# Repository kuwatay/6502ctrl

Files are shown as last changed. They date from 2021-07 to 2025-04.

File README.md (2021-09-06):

# 6502ctrl
AVR-based supervisor for a w65c02 microcomputer based on z80ctrl https://github.com/jblang/z80ctrl

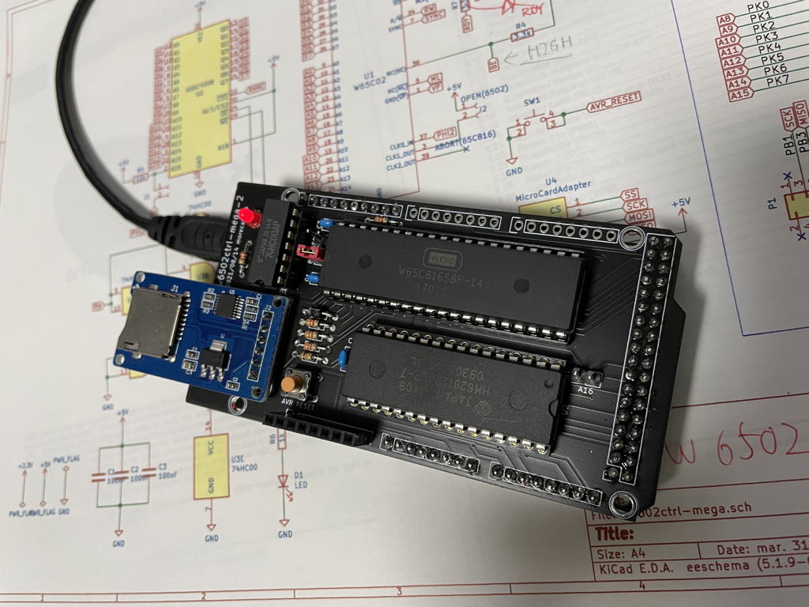
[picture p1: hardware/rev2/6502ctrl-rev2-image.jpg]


6502ctrl has the following features:
* Support W65C02 and 64KB(128KB) ram
* Console and other I/O are handled by DMA (ultra fast WAI instruction)
* Monitor with file management, memory inspector, and built-in 6502 disassembler
* Single-step debugging, breakpoints, and watchpoints to trace 6502 bus activity in real-time
* Arduino Shield style hardware (6502ctrl-mega)
* Flexible MIT-licensed firmware inhelited from z80ctrl

# Documentation

## Application
https://github.com/kuwatay/6502ctrl/wiki/Application

## Hardware note
https://github.com/kuwatay/6502ctrl/wiki/Hardware-of-6502ctrl-mega

## Supervisor sample session
https://github.com/kuwatay/6502ctrl/wiki/Sample-session-of--Supervisor

## DMA handling
https://github.com/kuwatay/6502ctrl/wiki/DMA-I-O-request

## MIT license
Permission is hereby granted, free of charge, to any person obtaining a copy of this software and associated documentation files (the "Software"), to deal in the Software without restriction, including without limitation the rights to use, copy, modify, merge, publish, distribute, sublicense, and/or sell copies of the Software, and to permit persons to whom the Software is furnished to do so, subject to the following conditions:

The above copyright notice and this permission notice shall be included in all copies or substantial portions of the Software.

THE SOFTWARE IS PROVIDED "AS IS", WITHOUT WARRANTY OF ANY KIND, EXPRESS OR IMPLIED, INCLUDING BUT NOT LIMITED TO THE WARRANTIES OF MERCHANTABILITY, FITNESS FOR A PARTICULAR PURPOSE AND NONINFRINGEMENT. IN NO EVENT SHALL THE AUTHORS OR COPYRIGHT HOLDERS BE LIABLE FOR ANY CLAIM, DAMAGES OR OTHER LIABILITY, WHETHER IN AN ACTION OF CONTRACT, TORT OR OTHERWISE, ARISING FROM, OUT OF OR IN CONNECTION WITH THE SOFTWARE OR THE USE OR OTHER DEALINGS IN THE SOFTWARE.

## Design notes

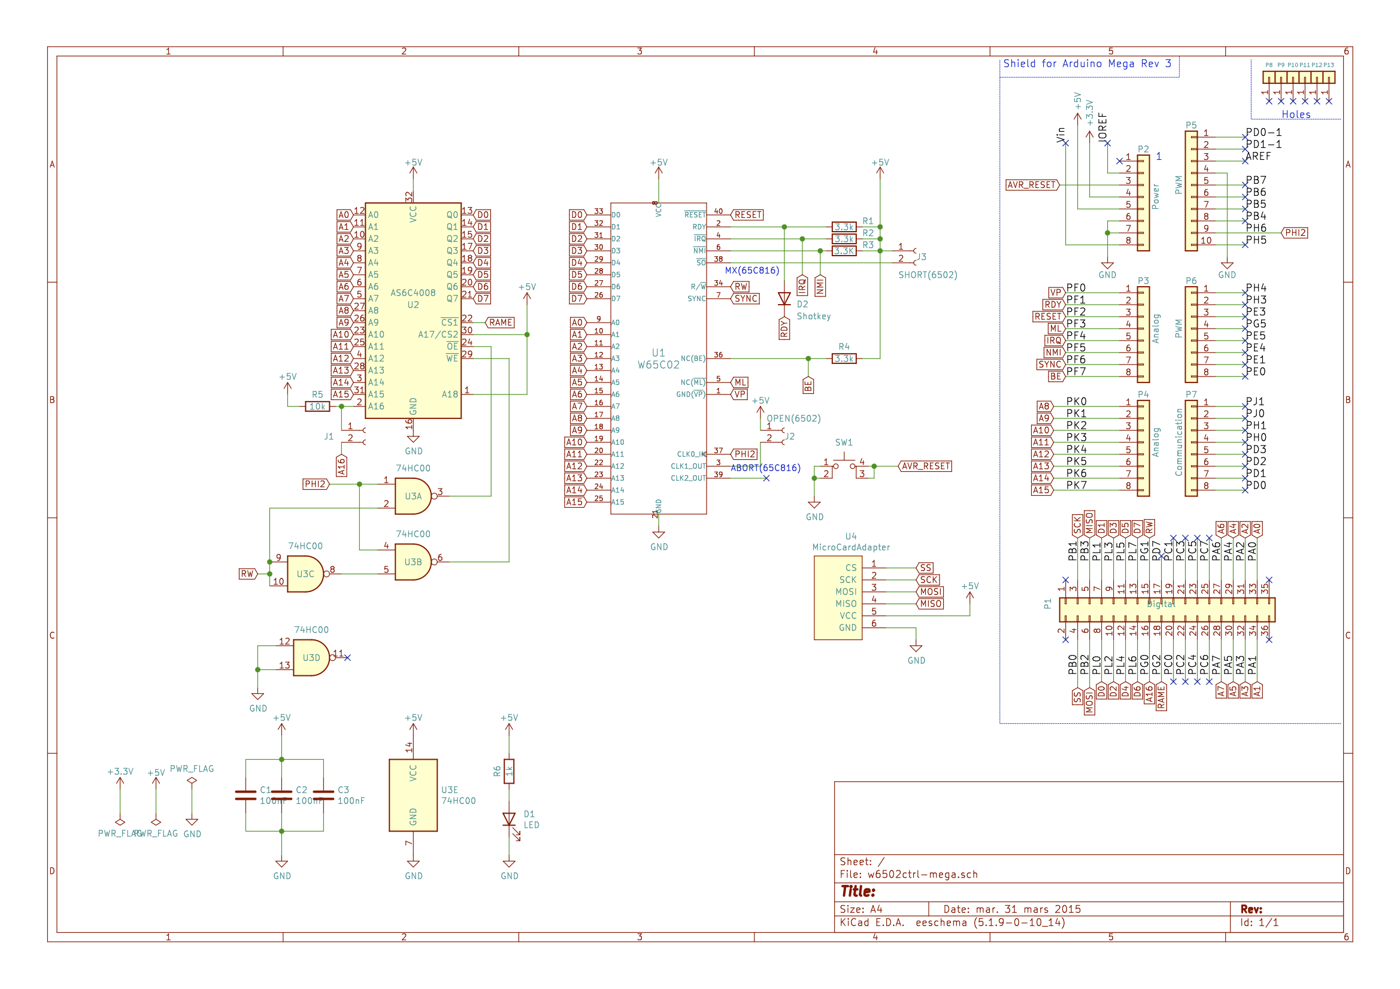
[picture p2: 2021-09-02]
hardware/rev2b/w65c02ctrl-mega2b-schematic.png

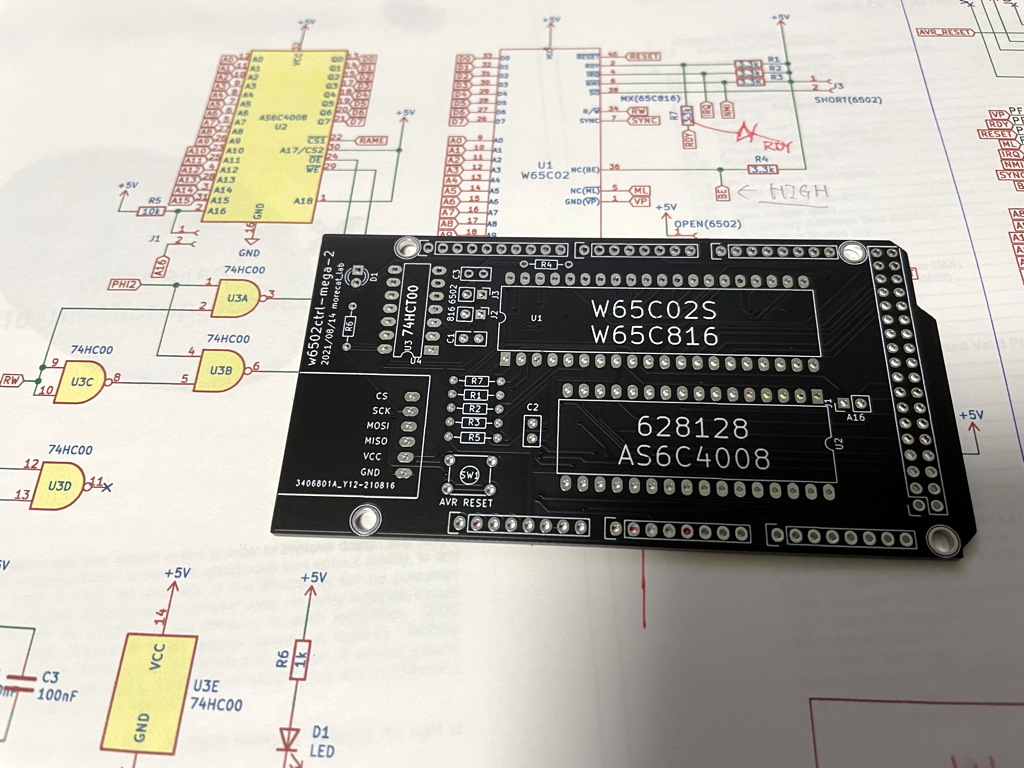
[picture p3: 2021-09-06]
hardware/rev2/6502ctrl-rev2-pcb.jpg

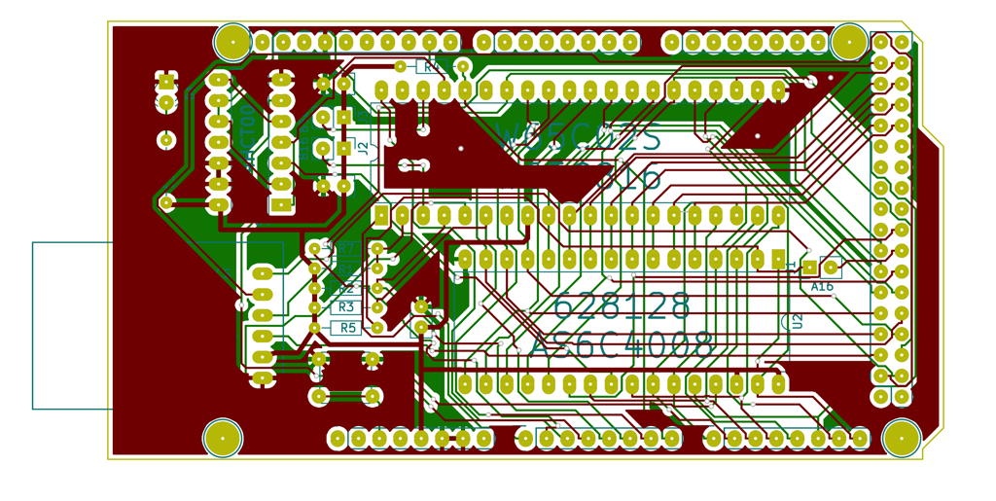
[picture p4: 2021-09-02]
hardware/rev2/6502ctrl-mega2-pcbimage.png

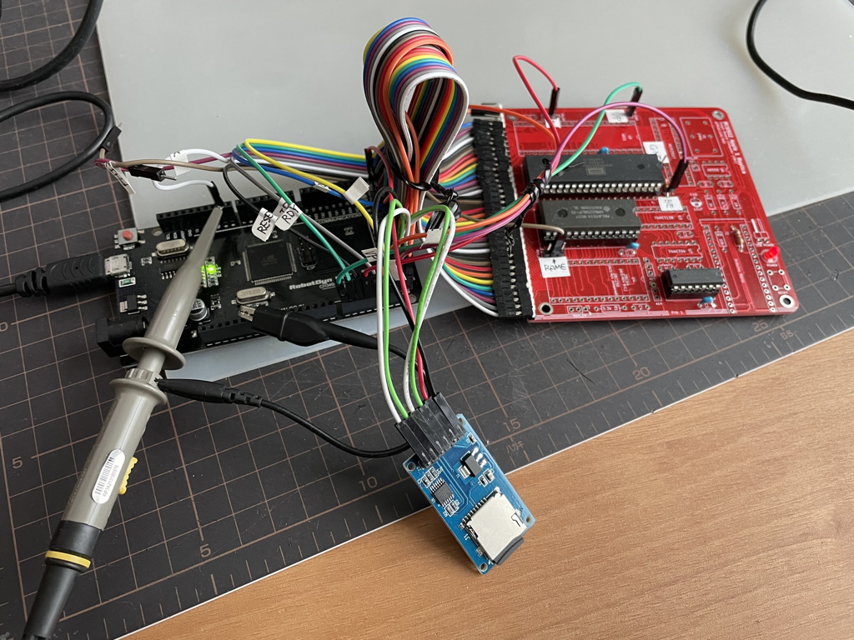
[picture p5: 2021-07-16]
hardware/prototype_6502ctrl.jpg

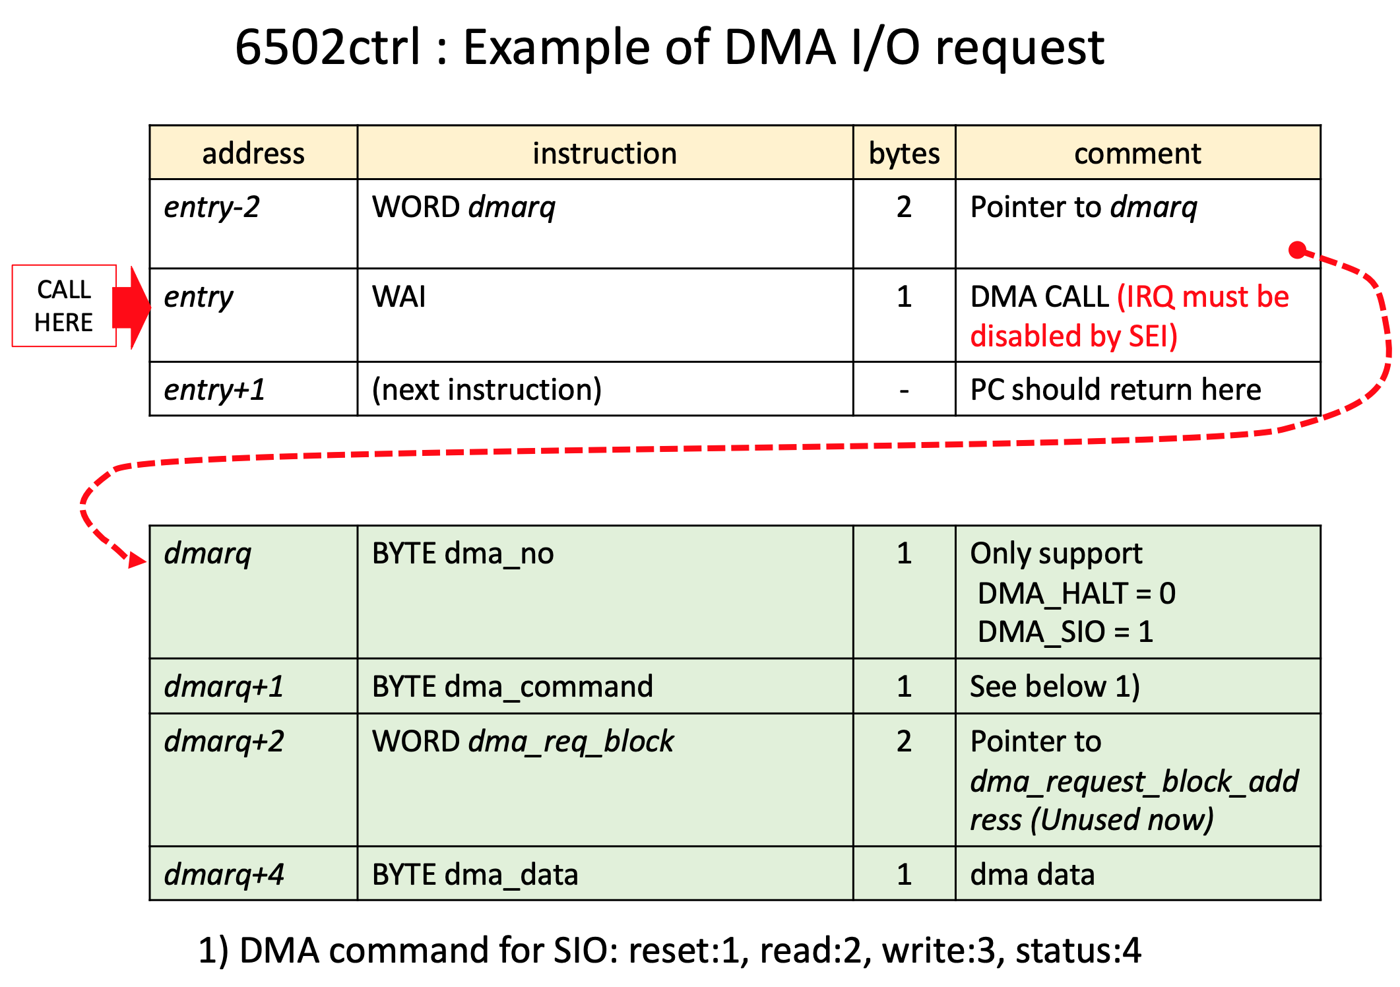
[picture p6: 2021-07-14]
DMA-request.png

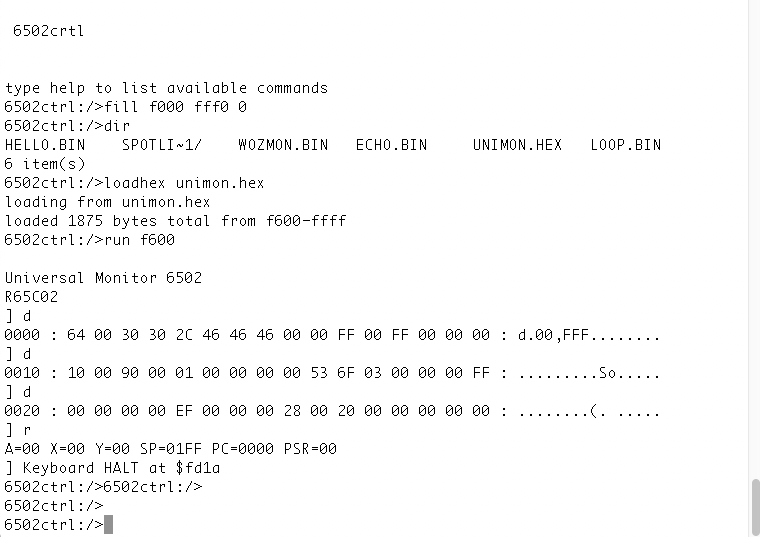
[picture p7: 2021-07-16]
examples/6502ctrl-univ-mon.png

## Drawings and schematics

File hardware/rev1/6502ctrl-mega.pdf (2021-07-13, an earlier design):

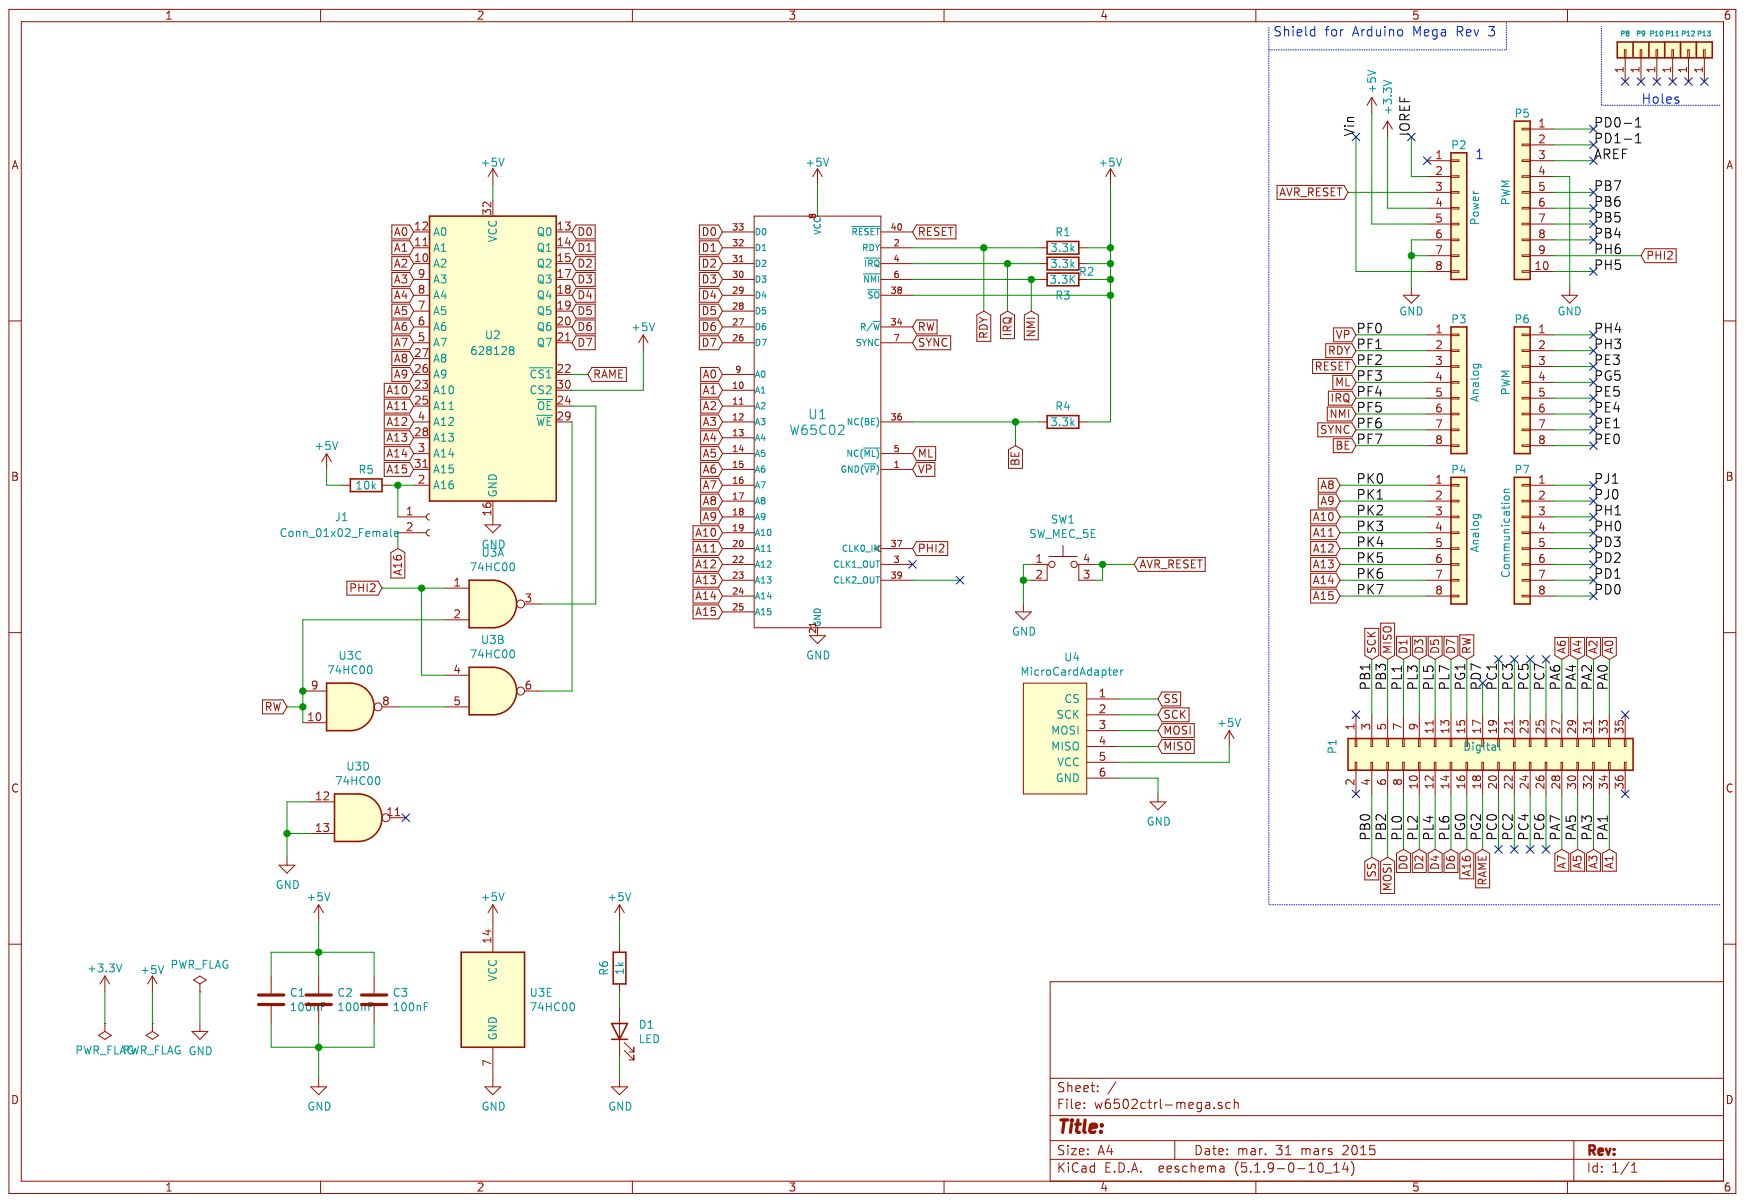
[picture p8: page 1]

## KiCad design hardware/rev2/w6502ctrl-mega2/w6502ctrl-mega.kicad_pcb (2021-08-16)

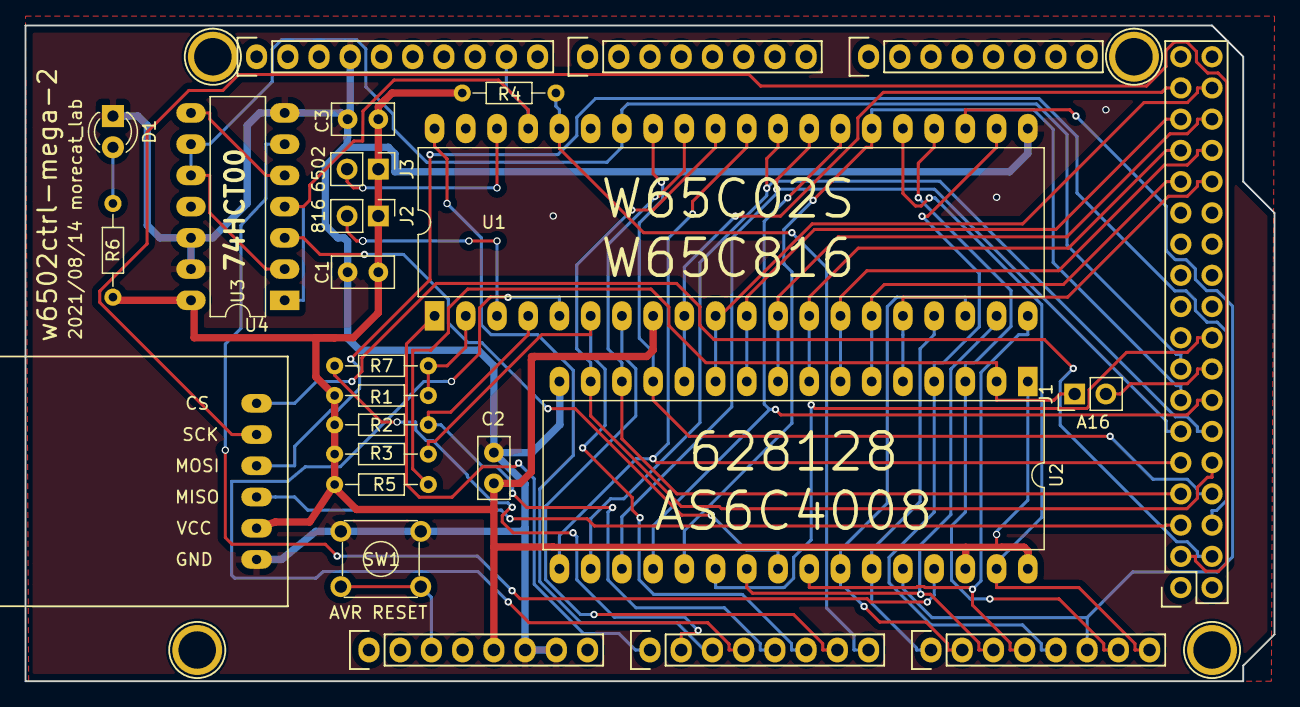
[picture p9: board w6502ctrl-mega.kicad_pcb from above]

Board: 2 copper layers, 101.6 x 53.3 mm, 30 parts (0 on the bottom side), 51 nets.

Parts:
C1, C2, C3: 100nF; C_Disc_D5.0mm_W2.5mm_P2.50mm
D1: LED; LED_D3.0mm
J1: Conn_01x02_Female; Pin_Header_Straight_1x02_Pitch2.54mm
J2: 816; Pin_Header_Straight_1x02_Pitch2.54mm
J3: 6502; Pin_Header_Straight_1x02_Pitch2.54mm
P1: Digital; Socket_Strip_Arduino_2x18
P2: Power; Socket_Strip_Arduino_1x08
P3, P4: Analog; Socket_Strip_Arduino_1x08
P5: PWM; Socket_Strip_Arduino_1x10
P6: PWM; Socket_Strip_Arduino_1x08
P7: Communication; Socket_Strip_Arduino_1x08
P8, P10, P11, P13: CONN_01X01; Arduino_1pin
R1, R2, R4, R7: 3.3k; R_Axial_DIN0204_L3.6mm_D1.6mm_P7.62mm_Horizontal
R3: 3.3K; R_Axial_DIN0204_L3.6mm_D1.6mm_P7.62mm_Horizontal
R5: 10k; R_Axial_DIN0204_L3.6mm_D1.6mm_P7.62mm_Horizontal
R6: 1k; R_Axial_DIN0204_L3.6mm_D1.6mm_P7.62mm_Horizontal
SW1: SW_MEC_5E; SW_TH_Tactile_Omron_B3F-10xx
U1: W65C02/816; DIP-40_W15.24mm_LongPads
U2: AS6C4008; DIP-32_W15.24mm_LongPads
U3: 74HC00; DIP-14_W7.62mm_LongPads
U4: MicroCardAdapter; MicroSDCardAdapter

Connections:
+5V: C1.1, C2.1, C3.1, J2.1, J3.1, P2.5, R1.1, R2.1, R3.1, R4.1, R5.2, R6.1, U1.8, U2.1, U2.30, U2.32, U3.14, U4.5
A0: P1.33, U1.9, U2.12
A1: P1.34, U1.10, U2.11
A2: P1.31, U1.11, U2.10
A3: P1.32, U1.12, U2.9
A4: P1.29, U1.13, U2.8
A5: P1.30, U1.14, U2.7
A6: P1.27, U1.15, U2.6
A7: P1.28, U1.16, U2.5
A8: P4.1, U1.17, U2.27
A9: P4.2, U1.18, U2.26
A10: P4.3, U1.19, U2.23
A11: P4.4, U1.20, U2.25
A12: P4.5, U1.22, U2.4
A13: P4.6, U1.23, U2.28
A14: P4.7, U1.24, U2.3
A15: P4.8, U1.25, U2.31
A16: J1.2, P1.16
AVR_RESET: P2.3, SW1.3, SW1.4
BE: P3.8, R4.2, U1.36
D0: P1.8, U1.33, U2.13
D1: P1.7, U1.32, U2.14
D2: P1.10, U1.31, U2.15
D3: P1.9, U1.30, U2.17
D4: P1.12, U1.29, U2.18
D5: P1.11, U1.28, U2.19
D6: P1.14, U1.27, U2.20
D7: P1.13, U1.26, U2.21
GND: C1.2, C2.2, C3.2, D1.1, P2.6, P2.7, P5.4, SW1.1, SW1.2, U1.21, U2.16, U3.7, U3.12, U3.13, U4.6
IRQ: P3.5, R2.2, U1.4
MISO: P1.5, U4.4
ML: P3.4, U1.5
MOSI: P1.6, U4.3
NMI: P3.6, R3.2, U1.6
unnamed: D1.2, R6.2
unnamed: J1.1, R5.1, U2.2
unnamed: J2.2, U1.3
unnamed: J3.2, U1.38
unnamed: R1.2, R7.1, U1.2
unnamed: U2.24, U3.3
unnamed: U2.29, U3.6
unnamed: U3.5, U3.8
PHI2: P5.9, U1.37, U3.1, U3.4
RAME: P1.18, U2.22
RDY: P3.2, R7.2
RESET: P3.3, U1.40
RW: P1.15, U1.34, U3.2, U3.9, U3.10
SCK: P1.3, U4.2
SS: P1.4, U4.1
SYNC: P3.7, U1.7
VP: P3.1, U1.1

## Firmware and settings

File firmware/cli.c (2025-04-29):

/* 6502ctrl (https://github.com/kuwatay/6502cttl)
 * Copyright 2021 Yoshitaka Kuwata a.k.a. morecat_lab
 *
 * based on z80ctrl (https://github.com/jblang/z80ctrl)
 * Copyright 2018 J.B. Langston
 *
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
 * THE SOFTWARE IS PROVIDED "AS IS", WITHOUT WARRANTY OF ANY KIND, EXPRESS OR
 * IMPLIED, INCLUDING BUT NOT LIMITED TO THE WARRANTIES OF MERCHANTABILITY, 
 * FITNESS FOR A PARTICULAR PURPOSE AND NONINFRINGEMENT. IN NO EVENT SHALL THE
 * AUTHORS OR COPYRIGHT HOLDERS BE LIABLE FOR ANY CLAIM, DAMAGES OR OTHER 
 * LIABILITY, WHETHER IN AN ACTION OF CONTRACT, TORT OR OTHERWISE, ARISING 
 * FROM, OUT OF OR IN CONNECTION WITH THE SOFTWARE OR THE USE OR OTHER 
 * DEALINGS IN THE SOFTWARE.
 */

/**
 * @file cli.c Monitor command-line interface
 */

#include <avr/pgmspace.h>
#include <avr/interrupt.h>
#include <stdint.h>
#include <stdio.h>
#include <string.h>
#include <stdlib.h>
#include <ctype.h>
#include <time.h>

#include "ff.h"
#include "bus.h"
#include "dmarq.h"
#include "w6502.h"
#include "ihex.h"
#include "util.h"
#include "disasm.h"
//#include "diskemu.h"
//#include "bdosemu.h"
#include "sioemu.h"
#include "diskio.h"
#include "uart.h"
#include "xmodem.h"
#include "filedma.h"
#ifdef USE_RTC
#include "rtc.h"
#endif
#ifdef SST_FLASH
#include "flash.h"
#endif
#include "ffwrap.h"

#ifdef HPDL1414
#include "hpdl1414.h"
#endif

/**
 * SD card filesystem
 */
FATFS fs;

/**
 * UART stdio stream
 */
FILE uart_str = FDEV_SETUP_STREAM(uart_putchar, uart_getchar, _FDEV_SETUP_RW);

uint8_t screenwidth = 80;
uint8_t screenheight = 24;

/**
 * Load an Intel HEX file from disk or stdin
 */
void cli_loadhex(int argc, char *argv[])
{
    FIL fil;
    FILE file;
    FRESULT fr;
    ihex_res result;
    if (argc < 2) {
        printf_P(PSTR("loading from console; enter blank line to cancel\n"));
        result = load_ihex(stdin);
    } else {
        printf_P(PSTR("loading from %s\n"), argv[1]);
        if ((fr = file_open(&fil, &file, argv[1], FA_READ)) != FR_OK)
            return;
        result = load_ihex(&file);
        file_close(&fil);
    }
    printf_P(PSTR("loaded %d bytes total from %04x-%04x"), result.total, result.min, result.max);
    if (result.errors > 0)
        printf_P(PSTR(" with %d errors"), result.errors);
    printf_P(PSTR("\n"));
}

/**
 * Save an Intel HEX file to disk or stdout
 */
void cli_savehex(int argc, char *argv[])
{
    FRESULT fr;
    FILE file;
    FIL fil;
    if (argc < 3) {
        printf_P(PSTR("usage: savehex <start> <end> [file]\n"));
        return;
    }
    uint32_t start = strtoul(argv[1], NULL, 16) & 0xfffff;
    uint32_t end = strtoul(argv[2], NULL, 16) & 0xfffff;
    if (argc == 4) {
        if ((fr = file_open(&fil, &file, argv[3], FA_WRITE | FA_CREATE_ALWAYS)) != FR_OK)
            return;
        if (save_ihex(start, end, &file) == EOF)
            printf_P(PSTR("error writing file"));
        file_close(&fil);
    } else {
        if (save_ihex(start, end, stdout) == EOF)
            printf_P(PSTR("error writing file"));
    }
}

#define MEM 0
#define TMS 1
#define FLASH 2

uint32_t loadbin(char *filename, uint8_t dest, int32_t start, uint32_t offset, uint32_t len)
{
    FIL fil;
    FRESULT fr;
    UINT br;
    uint8_t buf[512];
    uint16_t load = start;
    if (len == 0)
        len = 0x100000;
    if ((fr = file_open(&fil, NULL, filename, FA_READ)) != FR_OK)
        return -1;
    if ((fr = file_seek(&fil, offset)) == FR_OK) {
        if (start < 0) {
            // if starting address is not specified, get it from
            // the first two bytes of file a la C64 PRG files
            if (fr = file_read(&fil, &load, 2, &br) != FR_OK) {
                file_close(&fil);
                return 0;
            }
            start = load;
        }
        while ((fr = file_read(&fil, buf, sizeof buf, &br)) == FR_OK) {
            if (br > len)
                br = len;
            if (dest == MEM && br > 0) {
                mem_write_banked(start, buf, br);
            }
#ifdef SST_FLASH
            else if (dest == FLASH) {
                flash_write(start, buf, br);
            }
#endif
            if (br < sizeof buf)
                break;
            start += br;
            len -= br;
        }
    }
    file_close(&fil);
    return load;
}


/**
 * Load a binary file to specifie address from disk with optional offset and length
 */
void cli_loadbin(int argc, char *argv[])
{
    if (argc < 3) {
        printf_P(PSTR("usage: %s <start addr> <filename> [offset] [length]\n"), argv[0]);
        return;
    }
    uint8_t dest;
    if (strcmp_P(argv[0], PSTR("flash")) == 0)
        dest = FLASH;
    else if (strcmp_P(argv[0], PSTR("tmslbin")) == 0)
        dest = TMS;
    else
        dest = MEM;    
    uint32_t start = strtoul(argv[1], NULL, 16);
    char *filename = argv[2];
    uint32_t offset = 0;
    uint32_t len = 0;
    if (argc >= 4)
        offset = strtoul(argv[3], NULL, 16);
    if (argc >= 5)
        len = strtoul(argv[4], NULL, 16);
    loadbin(filename, dest, start, offset, len);
}

#if 0
#ifdef SST_FLASH
/**
 * Erase a flash sector or entire chip
 */
void cli_erase(int argc, char *argv[])
{
    if (argc < 2) {
        printf_P(PSTR("usage: erase <addr> | erase all\n"));
        return;
    }
    uint32_t addr;
    if (strcmp_P(argv[1], PSTR("all")) == 0)
        addr = 0x80000;
    else
        addr = strtoul(argv[1], NULL, 16);
    flash_erase(addr);
}
#endif
#endif

/**
 * Save an region of memory to a binary file on disk
 */
void cli_savebin(int argc, char *argv[])
{
    FRESULT fr;
    FILE file;
    FIL fil;
    UINT bw;
    uint16_t len = 256;
    uint8_t buf[256];
    if (argc < 4) {
        printf_P(PSTR("usage: savebin <start> <end> [file]\n"));
        return;
    }
    uint32_t start = strtoul(argv[1], NULL, 16) & 0xfffff;
    uint32_t end = strtoul(argv[2], NULL, 16) & 0xfffff;
    if ((fr = file_open(&fil, NULL, argv[3], FA_WRITE | FA_CREATE_ALWAYS)) == FR_OK) {
        while (start <= end) {
            if (end - start + 1 < len)
                len = end - start + 1;
            mem_read_banked(start, buf, len);
            if ((fr = file_write(&fil, buf, len, &bw)) != FR_OK)
                break;
            start += len;
        }
        file_close(&fil);
    }        
}

/**
 * Receive a file via xmodem
 */
void cli_xmrx(int argc, char *argv[])
{
    printf_P(PSTR("waiting for transfer to begin; press ^X twice to cancel\n"));
    xm_receive(argc - 1, &argv[1]);
}

/**
 * Transmit a file via xmodem
 */
void cli_xmtx(int argc, char *argv[])
{
    FIL fil;
    FILE file;
    FRESULT fr;
    UINT br;
    if (argc < 2) {
        printf_P(PSTR("usage: %s <file>\n"), argv[0]);
        return;
    }
    if ((fr = file_open(&fil, NULL, argv[1], FA_READ)) == FR_OK) {
        printf_P(PSTR("beginning transmission; press ^X twice to cancel\n"));
        xm_transmit(&fil);
        file_close(&fil);
    }
}


/**
 * Disassemble code from memory
 */
void cli_disasm(int argc, char *argv[])
{
    uint32_t start, end;
    if (argc < 2) {
        printf_P(PSTR("usage: disasm <start> [end]\n"));
        return;
    }
    start = strtoul(argv[1], NULL, 16) & 0xffff;
    if (argc < 3)
        end = start + 0xf;
    else
        end = strtoul(argv[2], NULL, 16) & 0xffff;
    disasm_mem(start, end);
}

/**
 * Generate a hex dump from memory
 */
void cli_dump(int argc, char *argv[])
{
  //    uint8_t tms = (strcmp_P(argv[0], PSTR("tmsdump")) == 0);
    if (argc < 2) {
        printf_P(PSTR("usage: %s [start] [end]\n"), argv[0]);
    }

    static uint32_t start = 0;
    uint32_t end = 0;
    if (argc >= 2)
        start = strtoul(argv[1], NULL, 16);
    if (argc >= 3)
        end = strtoul(argv[2], NULL, 16);
    
    uint8_t buf[16];

    uint8_t buflen = 16;
    if (screenwidth < 80)
        buflen = 8;

    if (end == 0)
        end = start + (screenheight - 3) * buflen;

    printf_P(PSTR("ADDR   "));
    for (uint8_t j = 0; j < buflen; j++) {
        printf("+%X ", j);
        if (j % 4 == 3 && screenwidth > 41)
            printf_P(PSTR(" "));
    }
    if (screenwidth > 40)
        printf_P(PSTR(" "));
    for (uint8_t j = 0; j < buflen; j++)
        printf_P(PSTR("%X"), j);
    printf_P(PSTR("\n"));

    
    for (uint32_t i = start; i <= end;) {
        printf_P(PSTR("%05lX  "), base_addr + i);
            mem_read_banked(i, buf, buflen);
        for (uint8_t j = 0; j < buflen; j++) {
            printf_P(PSTR("%02X "), buf[j]);
            if (j % 4 == 3 && screenwidth > 41)
                printf_P(PSTR(" "));
        }
        if (screenwidth > 40)
            printf_P(PSTR(" "));
        for (uint8_t j = 0; j < buflen; j++, i++) {
            if (0x20 <= buf[j] && buf[j] <= 0x7e)
                printf_P(PSTR("%c"), buf[j]);
            else
                printf_P(PSTR("."));
        }
        printf_P(PSTR("\n"));
    }
    start = end + buflen;
}

/**
 * Run the processor at full speed from an optional starting address
 */
void cli_run(int argc, char *argv[])
{
    if (argc >= 2) {
        uint32_t addr = strtoul(argv[1], NULL, 16) & 0xfffff;
        w6502_reset(addr);
    }
    w6502_run();
}


/**
 * Reset the processor and optionally set up a reset vector
 */
void cli_reset(int argc, char *argv[])
{
    uint32_t addr = 0;
    if (argc >= 2) {
        addr = strtoul(argv[1], NULL, 16) & 0xfffff;
    }
    w6502_reset(addr);
}

/**
 * Run the processor with debugging enabled from an optional starting address
 */
void cli_debug(int argc, char *argv[])
{
    if (argc >= 2) {
        uint32_t addr = strtoul(argv[1], NULL, 16) & 0xfffff;
        w6502_reset(addr);
    }
    w6502_debug(1);
}

/**
 * Run the processor for a specified number of instructions
 */
void cli_step(int argc, char *argv[])
{
    uint32_t cycles = 1;
    if (argc >= 2)
        cycles = strtoul(argv[1], NULL, 10);            
    w6502_debug(cycles);
}

/**
 * Reduce the W6502 clock speed by the specified factor
 */
void cli_clkdiv(int argc, char *argv[])
{
    uint8_t tmp = 0;
    if (argc >= 2)
        tmp = strtoul(argv[1], NULL, 10);
    if (tmp > 1)
        clkdiv = tmp;
    else
        printf_P(PSTR("usage: clkdiv <divider>; minimum divider is 2\n"));
    uint16_t freq = F_CPU / clkdiv / 1000;
    printf_P(PSTR("current speed is %u.%03u MHz (clkdiv=%d)\n"), freq/1000, freq-(freq/1000)*1000, clkdiv);
}

/**
 * Set screen size
 */
void cli_screen(int argc, char *argv[])
{
    uint8_t tmpwidth = 0, tmpheight = 0;
    if (argc >= 2)
        tmpwidth = strtoul(argv[1], NULL, 10);
    if (argc >= 3)
        tmpheight = strtoul(argv[2], NULL, 10);
    if (tmpwidth >= 40)
        screenwidth = tmpwidth;
    if (tmpheight >= 24)
        screenheight = tmpheight;
        printf_P(PSTR("usage: screen <width> <height>\n"));
    uint16_t freq = F_CPU / clkdiv / 1000;
    printf_P(PSTR("current screen size is %dx%d\n"), screenwidth, screenheight);
}

/**
 * Interrogate or set breakpoint and watch ranges
 */
void cli_breakwatch(int argc, char *argv[])
{
    range *ranges;
    uint8_t type;

    if (strcmp_P(argv[0], PSTR("break")) == 0)
        ranges = breaks;
    else
        ranges = watches;
    
    // If no parameters given, show current status
    if (argc == 1) {
        printf_P(PSTR("%s status:\n"), argv[0]);
        for (uint8_t i = 0; i < DEBUGCNT; i++) {
            if (!ENABLED(ranges, i))
                printf_P(PSTR("\t%S\tdisabled\n"), strlookup(debug_names, i));
            else
                printf_P(PSTR("\t%S\t%04x-%04x\n"), strlookup(debug_names, i), ranges[i].start, ranges[i].end);
        }
        printf_P(PSTR("\nusage:\n\t%s <type> [start] [end]\n"), argv[0]);
        printf_P(PSTR("\t%s <type> off to disable type\n"), argv[0]);
        printf_P(PSTR("\t%s off to disable all\n"), argv[0]);
        return;
    }
    if (strcmp_P(argv[1], PSTR("off")) == 0) {
        // turn off all ranges
        for (uint8_t i = 0; i < DEBUGCNT; i++) {
            ranges[i].start = 0xffff;
            ranges[i].end = 0;
        }
        return;
    } else {
        // find the debugging type that the user specified
        for (type = 0; type < DEBUGCNT; type++)
            if (strcmp_P(argv[1], strlookup(debug_names, type)) == 0)
                break;
        if (type == DEBUGCNT) {
            printf_P(PSTR("error: unknown type\n"));
            return;
        }
        if (argc == 2) {
            // no range specified, enable for 0x0000-0xffff
            ranges[type].start = 0;
            ranges[type].end = 0xffff;
        } else if (argc >= 3) {
            if (strcmp_P(argv[2], PSTR("off")) == 0) {
                ranges[type].start = 0xffff;
                ranges[type].end = 0;
            } else {
                // get starting address
                ranges[type].start = strtoul(argv[2], NULL, 16);
                if (argc >= 4)
                    // get ending address if specified
                    ranges[type].end = strtoul(argv[3], NULL, 16);
                else
                    // if no ending address, start and end are the same
                    ranges[type].end = ranges[type].start;
            }
        }
    }
}

#if 0
/**
 * Enable/disable BDOS debug messages
 */
void cli_bdosdbg(int argc, char *argv[])
{
    if (argc == 2) {
        if (strcmp_P(argv[1], PSTR("on")) == 0)
            bdos_debug = 1;
        else if (strcmp_P(argv[1], PSTR("off")) == 0)
            bdos_debug = 0;
    }
    if (bdos_debug)
        printf("bdos debug is enabled\n");
    else
        printf("bdos debug is disabled\n");
}
#endif

/**
 * Enable/disable DMA debug messages
 */
void cli_dmadbg(int argc, char *argv[])
{
    if (argc == 2) {
        if (strcmp_P(argv[1], PSTR("on")) == 0)
            dma_debug = 1;
        else if (strcmp_P(argv[1], PSTR("off")) == 0)
            dma_debug = 0;
    }
    if (dma_debug)
        printf("dma debug is enabled\n");
    else
        printf("dma debug is disabled\n");
}

/**
 * Change default directory
 */
void cli_chdir(int argc, char *argv[])
{
 	FRESULT fr;

    if (argc < 2) {
        printf_P(PSTR("usage: cd <directory>\n"));
        return;
    }

    fr = f_chdir(argv[1]);
    if (fr)
        printf_P(PSTR("error changing directory: %S\n"), strlookup(fr_text, fr));
}

/**
 * Create a directory
 */
void cli_mkdir(int argc, char *argv[])
{
 	FRESULT fr;

    if (argc < 2) {
        printf_P(PSTR("usage: mkdir <dir>\n"));
        return;
    }

    for (uint8_t i = 1; i < argc; i++) {
        if (fr = f_mkdir(argv[i]))
            printf_P(PSTR("error making directory %s: %S\n"), argv[i], strlookup(fr_text, fr));
    }
}

/**
 * Show a directory of files on the SD Card
 */
void cli_dir(int argc, char *argv[])
{
    FRESULT fr;
    FILINFO finfo;
    DIR dir;
	UINT cnt;
    char *dirname;
    char *glob;
    char buf[14];

    if (argc == 1) {
        dirname = ".";
        glob = NULL;
    } else {
        dirname = argv[1];
        glob = file_splitpath(dirname);
    }

    if (glob == NULL) {
        fr = f_opendir(&dir, dirname);
        if (fr == FR_NO_PATH || fr == FR_INVALID_NAME) {
            glob = dirname;
            dirname = ".";
        } else if (fr != FR_OK) {
            printf_P(PSTR("error opening directory: %S\n"), strlookup(fr_text, fr));
            return;
        }
    }

    if (glob == NULL) {
        fr = f_readdir(&dir, &finfo);
    } else {
        fr = f_findfirst(&dir, &finfo, dirname, glob);
    }

    uint8_t maxcnt = screenwidth / 13;

    cnt = 0;
    for(;;) {
        if (fr != FR_OK) {
            printf_P(PSTR("error reading directory: %S\n"), strlookup(fr_text, fr));
            break;
        }
        if ((cnt % maxcnt == 0 && cnt != 0) || !finfo.fname[0])
            printf_P(PSTR("\n"));
        if (!finfo.fname[0]) 
            break;
        strcpy(buf, finfo.fname);
        if (finfo.fattrib & AM_DIR)
            strcat(buf, "/");
        printf_P(PSTR("%-13s"), buf);
        cnt++;
        if (glob == NULL)
            fr = f_readdir(&dir, &finfo);
        else
            fr = f_findnext(&dir, &finfo);
    }
    if (cnt)
        printf_P(PSTR("%u item(s)\n"), cnt);
    else
        printf_P(PSTR("file not found\n"));
    
    f_closedir(&dir);
}

void cli_copy(int argc, char *argv[])
{
    if (argc < 3) {
        printf_P(PSTR("usage: %s <src>... <dest>\n"), argv[0]);
        return;
    }
    file_iterate(file_copy, argc-2, &argv[1], argv[argc-1]);
}

void cli_ren(int argc, char *argv[])
{
    if (argc < 3) {
        printf_P(PSTR("usage: %s <src>... <dest>\n"), argv[0]);
        return;
    }
    file_iterate(file_rename, argc-2, &argv[1], argv[argc-1]);
}

void cli_del(int argc, char *argv[])
{
    if (argc < 2) {
        printf_P(PSTR("usage: %s <file>...\n"), argv[0]);
        return;
    }
    file_iterate(file_delete, argc-1, &argv[1], NULL);
}

/**
 * Fill memory with a specified byte for a specified range
 */
void cli_fill(int argc, char *argv[])
{
    if (argc != 4) {
        printf_P(PSTR("usage: fill <start> <end> <value>\n"));
        return;
    }
    //    uint8_t tms = (strcmp_P(argv[0], PSTR("tmsfill")) == 0);
    uint32_t start = strtoul(argv[1], NULL, 16) & 0xfffff;
    uint32_t end = strtoul(argv[2], NULL, 16) & 0xfffff;
    uint8_t buf[256];
    if (strcmp_P(argv[3], PSTR("asc")) == 0) {
        for (uint16_t i = 0; i < 256; i++)
            buf[i] = i;
    } else if (strcmp_P(argv[3], PSTR("desc")) == 0) {
        for (uint16_t i = 0; i < 256; i++)
            buf[i] = 255 - i;
    } else {
        uint8_t value = strtoul(argv[3], NULL, 16) & 0xff;
        for (uint16_t i = 0; i < 256; i++)
            buf[i] = value;
    }
    
    for (;;) {
        if (end - start > 256) {
                mem_write_banked(start, buf, 256);
            start += 256;
        } else {
                mem_write_banked(start, buf, end - start + 1);
            break;
        }
    }
}

/**
 * Poke values into memory
 */
void cli_poke(int argc, char *argv[])
{
    uint8_t value;
    if (argc < 2)
        printf_P(PSTR("usage: poke <start> [value...]\n"));
    uint32_t addr = strtoul(argv[1], NULL, 16);
    if (argc >= 3) {
        for (uint8_t i = 2; i < argc; i++) {
            value = strtoul(argv[i], NULL, 16) & 0xff;
            mem_write_banked(addr++, &value, 1);
        }
        return;
    }
    printf_P(PSTR("enter valid hex to replace; blank to leave unchanged; 'x' to exit.\n"));
    for (;;) {
        char buf[16];
        mem_read_banked(addr, &value, 1);
        printf_P(PSTR("%05lX=%02X : "), addr + base_addr, value);
        if (fgets(buf, sizeof buf - 1, stdin) == NULL) {
            break;
        } else {
            char *end;
            value = strtoul(buf, &end, 16);
            if (*buf == '\n' || *buf == '\r' || *buf == '\0') {
                addr++;
                continue;
            } else if (end == buf) {
                break;
            } else {
                mem_write_banked(addr, &value, 1);
                addr++;
            }
        }
    }
    
}

#if 0
#if defined(BANK_PORT) || defined(BANK_BASE)

/**
 * Set the base address in memory
 */
void cli_base(int argc, char *argv[])
{
    if (argc == 2) {
        if (base_addr & 0xFFFF != 0)
            printf_P(PSTR("base address must be a multiple of 0x10000"));
        else
            base_addr = strtoul(argv[1], NULL, 16) & 0xF0000;
    } else {
        printf_P(PSTR("current base address is %05lX\n"), base_addr);
    }
}
#endif
#endif

/**
 * Boot from a disk
 */
#if 0
void cli_boot(int argc, char*argv[])
{
    if (argc == 2) {
        drive_mount(0, argv[1]);
    }
    if(drive_bootload()) {
        w6502_reset(0);
        w6502_run();
    }
}
#endif

/**
 * Display the bus status
 */
void cli_bus(int argc, char *argv[]) 
{
  bus_stat status = bus_status();
  bus_log(status);
#ifdef HPDL1414
  hpdl1414_disp(status);
#endif
}

#if 0
/**
 * Mount a disk image
 */
void cli_mount(int argc, char *argv[])
{
    if (argc != 3) {
        printf_P(PSTR("usage: mount <drive #> <filename>\n"));
        return;
    }
    uint8_t drv = strtoul(argv[1], NULL, 10);
    char *filename = argv[2];
    drive_mount(drv, filename);
}
#endif

#if 0
/**
 * Unmount a disk image
 */
void cli_unmount(int argc, char *argv[])
{
    if (argc != 2) {
        printf_P(PSTR("usage: unmount <drive #>\n"));
        return;
    }
    uint8_t drv = strtoul(argv[1], NULL, 10);
    drive_unmount(drv);
}
#endif

#if 0
/**
 * Display or set the date on the RTC
 */
#ifdef USE_RTC
void cli_date(int argc, char *argv[])
{
    struct tm date;
    char datestr[30];
    if (argc < 8) {
        rtc_get_date(&date);
        printf_P(PSTR("The time is %d:%02d:%02d on %d/%d/%02d\n"), date.tm_hour, date.tm_min, date.tm_sec, date.tm_mon, date.tm_mday, date.tm_year);
        printf_P(PSTR("usage: date <yy mm dd wd hh mm ss>\n"));
        return;
    }

    date.tm_year = strtoul(argv[1], NULL, 10);
    date.tm_mon = strtoul(argv[2], NULL, 10);
    date.tm_mday = strtoul(argv[3], NULL, 10);
    date.tm_wday = strtoul(argv[4], NULL, 10);
    date.tm_hour = strtoul(argv[5], NULL, 10);
    date.tm_min = strtoul(argv[6], NULL, 10);
    date.tm_sec = strtoul(argv[7], NULL, 10);
    rtc_set_date(&date);
}
#endif
#endif
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
int main(void)
{
    FRESULT fr;

    uart_init(0, UBRR115200);
    uart_init(1, UBRR115200);
    stdout = stdin = &uart_str;

    disk_initialize(DRV_MMC);
    if ((fr = f_mount(&fs, "", 1)) != FR_OK)
      printf_P(PSTR("error mounting drive: %S\n"), strlookup(fr_text, fr));

    bus_init();

#ifdef HPDL1414    
    hpdl1414_init();
    hpdl1414_clear();
    hpdl1414_strcpy_P(PSTR("6502CTRL_RDY"));
#endif

    //cli_exec(AUTOEXEC);
    cli_loop();
}

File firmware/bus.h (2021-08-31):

/* 6502ctrl (https://github.com/kuwatay/6502cttl)
 * Copyright 2021 Yoshitaka Kuwata a.k.a. morecat_lab
 *
 * based on z80ctrl (https://github.com/jblang/z80ctrl)
 * Copyright 2018 J.B. Langston
 *
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
 * THE SOFTWARE IS PROVIDED "AS IS", WITHOUT WARRANTY OF ANY KIND, EXPRESS OR
 * IMPLIED, INCLUDING BUT NOT LIMITED TO THE WARRANTIES OF MERCHANTABILITY, 
 * FITNESS FOR A PARTICULAR PURPOSE AND NONINFRINGEMENT. IN NO EVENT SHALL THE
 * AUTHORS OR COPYRIGHT HOLDERS BE LIABLE FOR ANY CLAIM, DAMAGES OR OTHER 
 * LIABILITY, WHETHER IN AN ACTION OF CONTRACT, TORT OR OTHERWISE, ARISING 
 * FROM, OUT OF OR IN CONNECTION WITH THE SOFTWARE OR THE USE OR OTHER 
 * DEALINGS IN THE SOFTWARE.
 */

/**
 * @file bus.h Low-level control of the Z80 bus
 */

#ifndef BUS_H
#define BUS_H

#include <avr/io.h>

/**
 * Address Bus
 */

#define ADDRLO_DDR DDRA
#define ADDRLO_PORT PORTA
#define ADDRLO_PIN PINA

#ifdef MEGA
#define ADDRHI_DDR DDRK
#define ADDRHI_PORT PORTK
#define ADDRHI_PIN PINK
#else
#define ADDRHI_DDR DDRC
#define ADDRHI_PORT PORTC
#define ADDRHI_PIN PINC
#endif

#define ADDR_INPUT (ADDRLO_DDR = 0x00, ADDRHI_DDR = 0x00)
#define ADDR_OUTPUT (ADDRLO_DDR = 0xFF, ADDRHI_DDR = 0xff)

#define GET_ADDRLO ADDRLO_PIN
#define SET_ADDRLO(addr) ADDRLO_PORT = (addr)

#define GET_ADDRHI ADDRHI_PIN
#define SET_ADDRHI(addr) ADDRHI_PORT = (addr)

#define GET_ADDR (GET_ADDRLO | (GET_ADDRHI << 8))
#define SET_ADDR(addr) (SET_ADDRLO((addr) & 0xFF), SET_ADDRHI((addr) >> 8))

/**
 * Data Bus
 */

#define DATA_DDR DDRL
#define DATA_PORT PORTL
#define DATA_PIN PINL

#define DATA_INPUT DATA_DDR = 0x00
#define DATA_OUTPUT DATA_DDR = 0xFF
#define GET_DATA DATA_PIN
#define SET_DATA(data) DATA_PORT = (data)

/**
 * PORTG Flags
 */
#define RAME (1 << 2)
#define RAME_HI PORTG |= RAME
#define RAME_LO PORTG &= ~RAME
#define RAME_OUTPUT DDRG |= RAME
#define RAME_INPUT DDRG &= ~RAME
#define RAME_STATUS (status.flags2 & RAME)

#define RW (1 << 1)
#define GET_RW (PING & RW)
#define RW_HI PORTG |= RW
#define RW_LO PORTG &= ~RW
#define RW_OUTPUT DDRG |= RW
#define RW_INPUT DDRG &= ~RW
#define RW_STATUS (status.flags2 & RW)

#define CTRLG_OUTPUT_INIT DDRG |= (RW | RAME)
#define CTRLG_MASK (RAME | RW)
/**
 * CONTROL_PORT Flags
 */
#ifdef MEGA
// Arduino Mega Shield version
#define CONT_PORT PORTF
#define CONT_DDR  DDRF
#define CONT_PIN  PINF
#else
// BREADBOARD VERSION USE PORTK
#define CONT_PORT PORTK
#define CONT_DDR  DDRK
#define CONT_PIN  PINK
#endif

#define VP (1 << 0)
#define GET_VP (CONT_PIN & VP)
#define VP_INPUT CONT_DDR &= ~VP
#define VP_STATUS (status.flags & VP)

#define RDY (1 << 1)
#define GET_RDY (CONT_PIN & RDY)
#define RDY_HI CONT_PORT |= RDY
#define RDY_LO CONT_PORT &= ~RDY
#define RDY_OUTPUT CONT_DDR |= RDY
#define RDY_INPUT CONT_DDR &= ~RDY
#define RDY_STATUS (status.flags & RDY)

#define RESET (1 << 2)
#define GET_RESET (CONT_PIN & RESET)
#define RESET_HI CONT_PORT |= RESET
#define RESET_LO CONT_PORT &= ~RESET
#define RESET_OUTPUT CONT_DDR |= RESET
#define RESET_INPUT CONT_DDR &= ~RESET
#define RESET_STATUS (status.flags & RESET)

#define MLB (1 << 3)
#define GET_MLB (CONT_PIN & MLB)
#define MLB_INPUT CONT_DDR &= ~MLB
#define MLB_STATUS (status.flags & MLB)

#define IRQ (1 << 4)
#define GET_IRQ (CONT_PIN & IRQ)
#define IRQ_HI CONT_PORT |= IRQ
#define IRQ_LO CONT_PORT &= ~IRQ
#define IRQ_OUTPUT CONT_DDR |= IRQ
#define IRQ_INPUT CONT_DDR &= ~IRQ
#define IRQ_STATUS (status.flags & IRQ)

#define NMI (1 << 5)
#define GET_NMI (CONT_PIN & NMI)
#define NMI_HI CONT_PORT |= NMI
#define NMI_LO CONT_PORT &= ~NMI
#define NMI_OUTPUT CONT_DDR |= NMI
#define NMI_INPUT CONT_DDR &= ~NMI
#define NMI_STATUS (status.flags & NMI)

#define SYNC (1 << 6)
#define GET_SYNC (CONT_PIN & SYNC)
#define SYNC_INPUT CONT_DDR &= ~SYNC
#define SYNC_STATUS (status.flags & SYNC)

#define BE (1 << 7)
#define GET_BE (CONT_PIN & BE)
#define BE_HI CONT_PORT |= BE
#define BE_LO CONT_PORT &= ~BE
#define BE_OUTPUT CONT_DDR |= BE
#define BE_INPUT CONT_DDR &= ~BE
#define BE_STATUS (status.flags & BE)

#define CTRLK_OUTPUT_INIT CONT_DDR |= (RESET | BE)


/* PORT H */
#define PHI2 (1 << 6)
#define GET_PHI2 (PINH & PHI2)
#define PHI2_HI PORTH |= PHI2
#define PHI2_LO PORTH &= ~PHI2
#define PHI2_TOGGLE PINH |= PHI2
#define PHI2_STATUS (status.flags2 & PHI2)

#define CTRLH_OUTPUT_INIT DDRH |= PHI2
#define CTRLH_MASK PHI2
#define GET_BUSACK (0) // DUMMY

/**
 * Complete bus status all in one place
 */
typedef struct {
        uint8_t flags;
        uint8_t flags2;
        uint16_t addr;
        uint8_t data;
} bus_stat;

extern uint8_t clkdiv;
extern uint32_t base_addr;

void clk_cycle(uint8_t cycles);
void clk_run(void);
void clk_stop(void);

uint8_t bus_request(void);
void bus_release(void);
void bus_init(void);

bus_stat bus_status(void);
bus_stat bus_status_fast(void);
void bus_log(bus_stat status);

uint8_t io_out(uint8_t addr, uint8_t value);
uint8_t io_in(uint8_t addr);

#if defined(BANK_PORT) || defined(BANK_BASE)
void mem_bank(uint8_t bank, uint8_t page);
void mem_bank_addr(uint32_t addr);
#else
#define mem_bank(bank, page)
#define mem_bank_addr(addr)
#endif

typedef void (*pagefunc_t)(uint8_t, uint8_t, void*);
void mem_read_page(uint8_t start, uint8_t end, void *buf);
void mem_write_page(uint8_t start, uint8_t end, void *buf);
void mem_write_page_P(uint8_t start, uint8_t end, void *buf);
void mem_iterate(uint16_t start, uint16_t end, pagefunc_t dopage, void *buf);
void mem_iterate_banked(uint32_t start, uint32_t end, pagefunc_t dopage, void *buf);

#define mem_read(addr, buf, len) mem_iterate((addr), ((addr) + ((len) - 1)), mem_read_page, (buf));
#define mem_write(addr, buf, len) mem_iterate((addr), ((addr) + ((len) - 1)), mem_write_page, (buf));
#define mem_write_P(addr, buf, len) mem_iterate((addr), ((addr) + ((len) - 1)), mem_write_page_P, (void *)(buf));

#define mem_read_banked(addr, buf, len) mem_iterate_banked((addr), ((addr) + ((len) - 1)), mem_read_page, (buf));
#define mem_write_banked(addr, buf, len) mem_iterate_banked((addr), ((addr) + ((len) - 1)), mem_write_page, (buf));
#define mem_write_banked_P(addr, buf, len) mem_iterate_banked((addr), ((addr) + ((len) - 1)), mem_write_page_P, (void *)(buf));


#endif

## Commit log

2021-07-13 upload hardware and examples
    [w6502ctrl-mega.sch, w6502ctrl-mega_routed.kicad_pcb]
2021-07-22 add OSI_BASIC
    [osi_bas.cfg]
2021-07-24 fix bus.s for mega pin assign
    adjust pin assign for 6502ctrl-mega
2021-08-16 upload rev2 hardware
    [w6502ctrl-mega.sch, w6502ctrl-mega_routed.kicad_pcb]
2021-08-16 update rev2 hardware
    update rev2 hardware
    [w6502ctrl-mega.kicad_pcb]
2021-08-26 add HPDL1414 display support
    add HPDL1414 display shield support
    spell correction
    [bus.h, cli.c, hpdl1414.h]
2021-09-02 arrange folder & upload rev2b schematic
    [w6502ctrl-mega.kicad_pcb, w6502ctrl-mega.sch, w6502ctrl-mega_routed.kicad_pcb]
2021-09-06 add rev2 board images
